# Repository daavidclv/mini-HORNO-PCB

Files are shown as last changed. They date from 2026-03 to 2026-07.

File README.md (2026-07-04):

# 🔥 Mini Horno — Diseño de PCB en KiCad

Diseño completo de PCB para un mini horno, desde el esquemático hasta los ficheros de fabricación (Gerbers).

## 📋 Descripción

Proyecto de diseño electrónico centrado en la placa de control de un mini horno: esquemático, layout, y generación de todos los archivos necesarios para su fabricación (Gerbers y taladros). Incluye la PCB ya fabricada y montada.

## 🛠️ Stack técnico

- **Diseño de PCB:** KiCad (esquemático + layout)
- **Fabricación:** Gerbers (RS-274X) + ficheros de taladro (PTH/NPTH)

## 📁 Estructura del repositorio

- `Horno.kicad_pro` / `Horno.kicad_sch` / `Horno.kicad_pcb` — proyecto KiCad completo (esquemático + layout)
- `Horno-*.gbr` — Gerbers de cada capa (cobre, máscara, pasta, serigrafía, corte)
- `Horno-PTH.drl` / `Horno-NPTH.drl` — ficheros de taladro
- `HornoGBR.zip` — paquete de fabricación listo para enviar al fabricante de PCBs

## 📸 Resultado

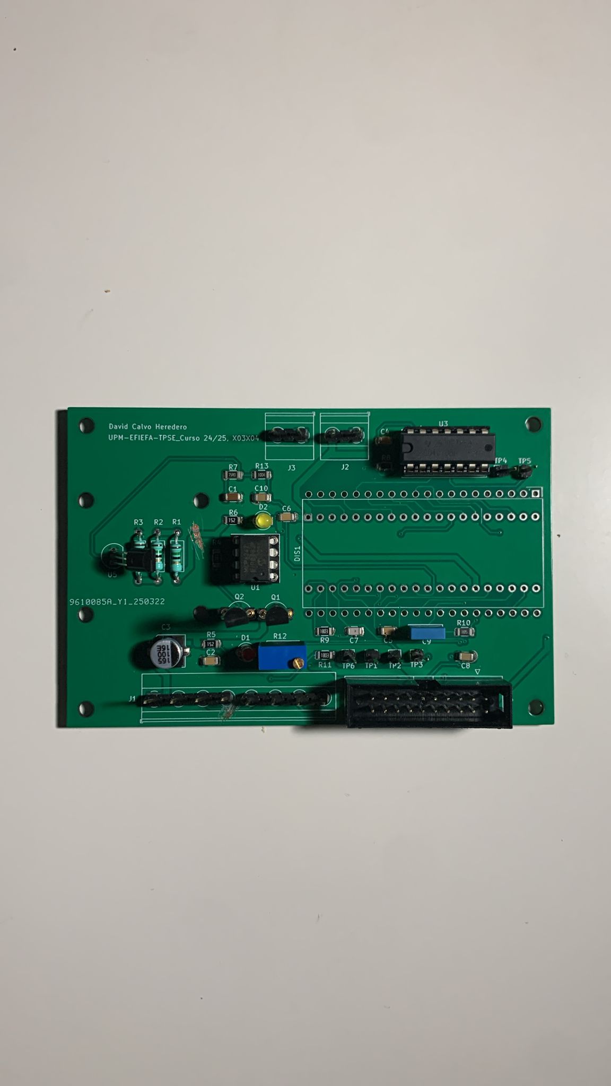
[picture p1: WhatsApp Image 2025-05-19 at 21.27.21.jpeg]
PCB del mini horno montada

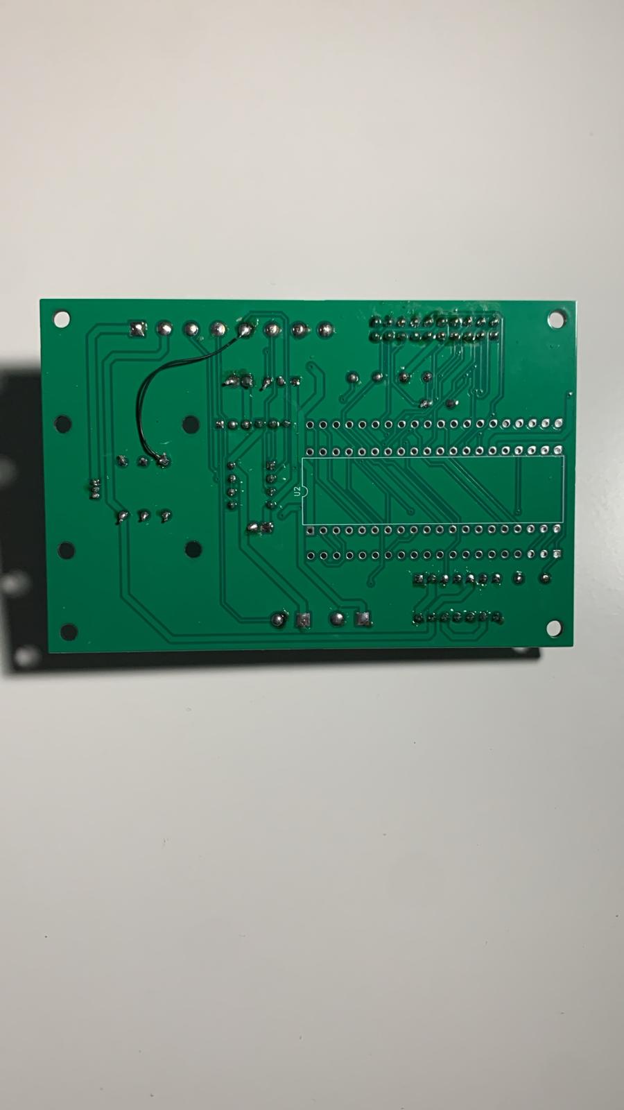
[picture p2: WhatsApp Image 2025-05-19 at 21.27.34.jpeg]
Detalle de la PCB


## 🎯 Lo más complejo del proyecto

- Diseño del layout considerando disipación térmica y separación de pistas de potencia
- Preparación del paquete completo de fabricación (Gerbers + taladros) sin errores de DRC

## 👤 Autor

David Calvo Heredero — [LinkedIn](https://www.linkedin.com/in/david-calvo-heredero-20b20a33a) · [GitHub](https://github.com/daavidclv)

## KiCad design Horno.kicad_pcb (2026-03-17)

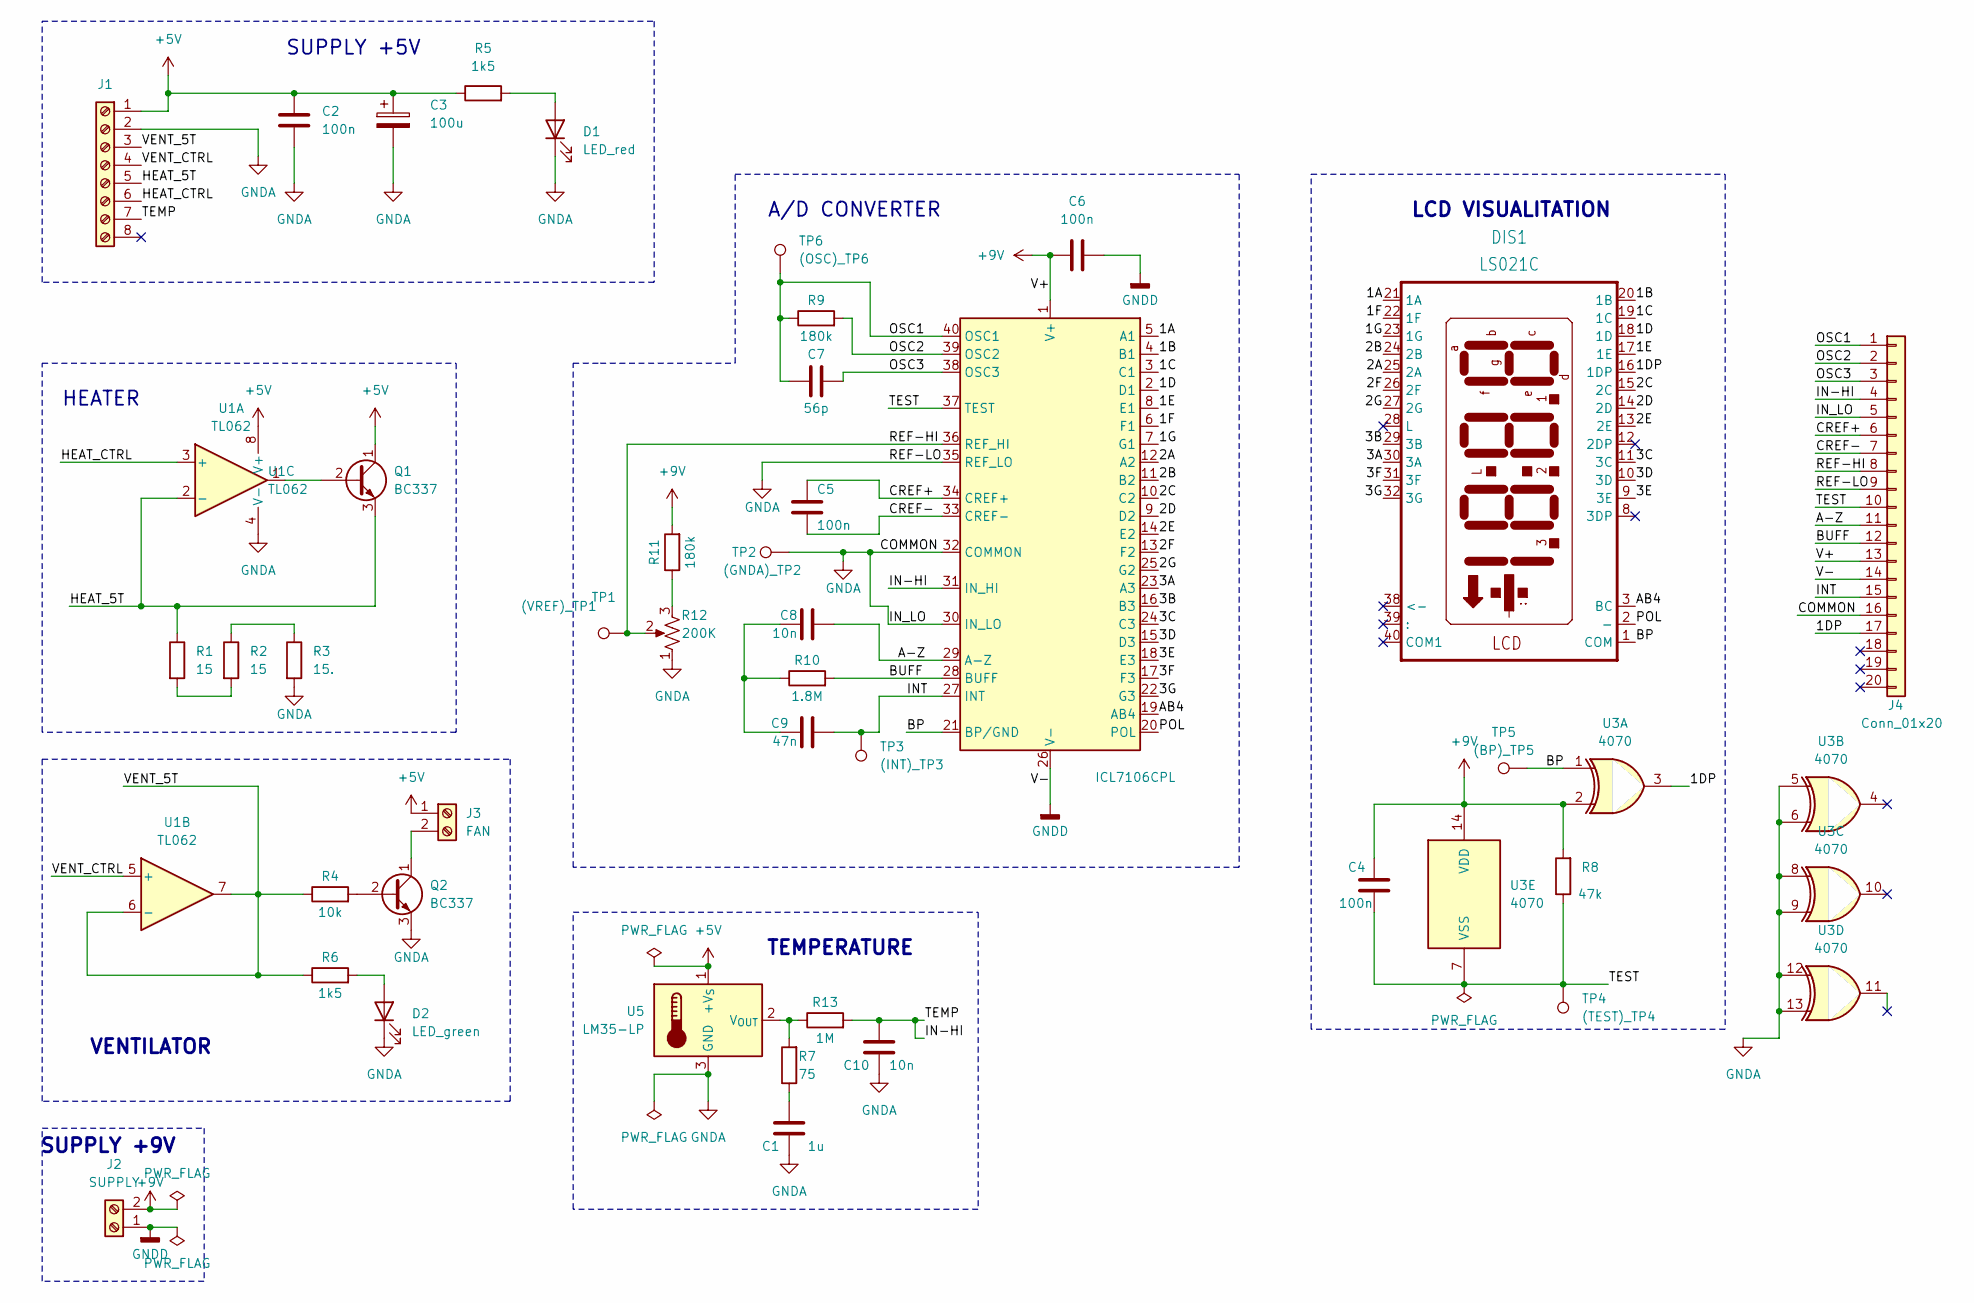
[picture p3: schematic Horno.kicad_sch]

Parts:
C1: 1u; C_1206_3216Metric
C2, C4, C5, C6: 100n; C_1206_3216Metric
C3: 100u; CP_Elec_5x3.9
C7: 56p; C_1206_3216Metric
C8, C10: 10n; C_1206_3216Metric
C9: 47n; C_Rect_L7.0mm_W2.5mm_P5.00mm
D1: LED_red; LED_D3.0mm
D2: LED_green; LED_D3.0mm
DIS1: LS021C; DELS021-XX-XX
J1: TerminalBlock_Phoenix_MKDS-1,5-8-5.08_1x08_P5.08mm_Horizont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
J2: SUPPLY; TerminalBlock_Phoenix_MKDS-1,5-2-5.08_1x02_P5.08mm_Horizont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
J3: FAN; TerminalBlock_Phoenix_MKDS-1,5-2-5.08_1x02_P5.08mm_Horizont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
J4: Conn_01x20; IDC-Header_2x10_P2.54mm_Vertical
Q1: BC337; TO-92L_Inline_Wide
Q2: BC337; TO-92_Inline_Wide
R1, R2: 15; R_Axial_DIN0207_L6.3mm_D2.5mm_P10.16mm_Horizontal
R3: 15.; R_Axial_DIN0207_L6.3mm_D2.5mm_P10.16mm_Horizontal
R4: 10k; R_1206_3216Metric
R5, R6: 1k5; R_1206_3216Metric
R7: 75; R_1206_3216Metric
R8: 47k; R_1206_3216Metric
R9, R11: 180k; R_1206_3216Metric
R10: 1.8M; R_1206_3216Metric
R12: 200K; Potentiometer_Bourns_3266Y_Vertical
R13: 1M; R_1206_3216Metric
TP1: (VREF)_TP1; Pin_D0.9mm_L10.0mm_W2.4mm_FlatFork
TP2: (GNDA)_TP2; Pin_D0.9mm_L10.0mm_W2.4mm_FlatFork
TP3: (INT)_TP3; Pin_D0.9mm_L10.0mm_W2.4mm_FlatFork
TP4: (TEST)_TP4; Pin_D0.9mm_L10.0mm_W2.4mm_FlatFork
TP5: (BP)_TP5; Pin_D0.9mm_L10.0mm_W2.4mm_FlatFork
TP6: (OSC)_TP6; Pin_D0.9mm_L10.0mm_W2.4mm_FlatFork
U1: TL062; DIP-8_W7.62mm_Socket
U2: ICL7106CPL; DIP-40_W15.24mm
U3: 4070
U5: LM35-LP; TO-92_Inline

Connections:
+5V: C2.1, C3.1, J1.1, J3.1, Q1.1 (C), R5.1, U1.8 (V+), U5.1 (+V_{S})
+9V: C4.1, C6.1, J2.2, J4.13, R8.2, R11.2, U2.1 (V+), U3.2, U3.14 (VDD)
/1A: DIS1.21 (1A), U2.5 (A1)
/1B: DIS1.20 (1B), U2.4 (B1)
/1C: DIS1.19 (1C), U2.3 (C1)
/1D: DIS1.18 (1D), U2.2 (D1)
/1DP: DIS1.16 (1DP), J4.17, U3.3
/1E: DIS1.17 (1E), U2.8 (E1)
/1F: DIS1.22 (1F), U2.6 (F1)
/1G: DIS1.23 (1G), U2.7 (G1)
/2A: DIS1.25 (2A), U2.12 (A2)
/2B: DIS1.24 (2B), U2.11 (B2)
/2C: DIS1.15 (2C), U2.10 (C2)
/2D: DIS1.14 (2D), U2.9 (D2)
/2E: DIS1.13 (2E), U2.14 (E2)
/2F: DIS1.26 (2F), U2.13 (F2)
/2G: DIS1.27 (2G), U2.25 (G2)
/3A: DIS1.30 (3A), U2.23 (A3)
/3B: DIS1.29 (3B), U2.16 (B3)
/3C: DIS1.11 (3C), U2.24 (C3)
/3D: DIS1.10 (3D), U2.15 (D3)
/3E: DIS1.9 (3E), U2.18 (E3)
/3F: DIS1.31 (3F), U2.17 (F3)
/3G: DIS1.32 (3G), U2.22 (G3)
/A-Z: C8.1, J4.11, U2.29 (A-Z)
/AB4: DIS1.3 (BC), U2.19 (AB4)
/BP: DIS1.1 (COM), TP5.1, U2.21 (BP/GND), U3.1
/BUFF: J4.12, R10.2, U2.28 (BUFF)
/CREF+: C5.2, J4.6, U2.34 (CREF+)
/CREF-: C5.1, J4.7, U2.33 (CREF-)
/HEAT_CTRL: J1.6, U1.3 (+)
/IN-HI: C10.1, J1.7, J4.4, R13.2, U2.31 (IN_HI)
/INT: C9.1, J4.15, TP3.1, U2.27 (INT)
/OSC1: C7.1, J4.1, R9.1, TP6.1, U2.40 (OSC1)
/OSC2: J4.2, R9.2, U2.39 (OSC2)
/OSC3: C7.2, J4.3, U2.38 (OSC3)
/POL: DIS1.2 (-), U2.20 (POL)
/REF-HI: J4.8, R12.2, TP1.1, U2.36 (REF_HI)
/TEST: C4.2, J4.10, R8.1, TP4.1, U2.37 (TEST), U3.7 (VSS)
/VENT_CTRL: J1.4, U1.5 (+)
GNDA: C1.2, C2.2, C3.2, C10.2, D1.1 (K), D2.1 (K), J1.2, J4.5, J4.9, J4.16, Q2.3 (E), R3.2, R12.1, TP2.1, U1.4 (V-), U2.30 (IN_LO), U2.32 (COMMON), U2.35 (REF_LO), U3.5, U3.6, U3.8, U3.9, U3.12, U3.13, U5.3 (GND)
GNDD: C6.2, J2.1, J4.14, U2.26 (V-)
unnamed: C1.1, R7.1
unnamed: C8.2, C9.2, R10.1
unnamed: D1.2 (A), R5.2
unnamed: D2.2 (A), R6.2
unnamed: J3.2, Q2.1 (C)
unnamed: Q1.2 (B), U1.1
unnamed: Q2.2 (B), R4.2
unnamed: R1.2, R2.2
unnamed: R2.1, R3.1
unnamed: R11.1, R12.3
unnamed: R7.2, R13.1, U5.2 (V_{OUT})

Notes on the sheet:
A/D CONVERTER
TEMPERATURE
VENTILATOR
LCD VISUALITATION
SUPPLY +9V
HEATER
SUPPLY +5V

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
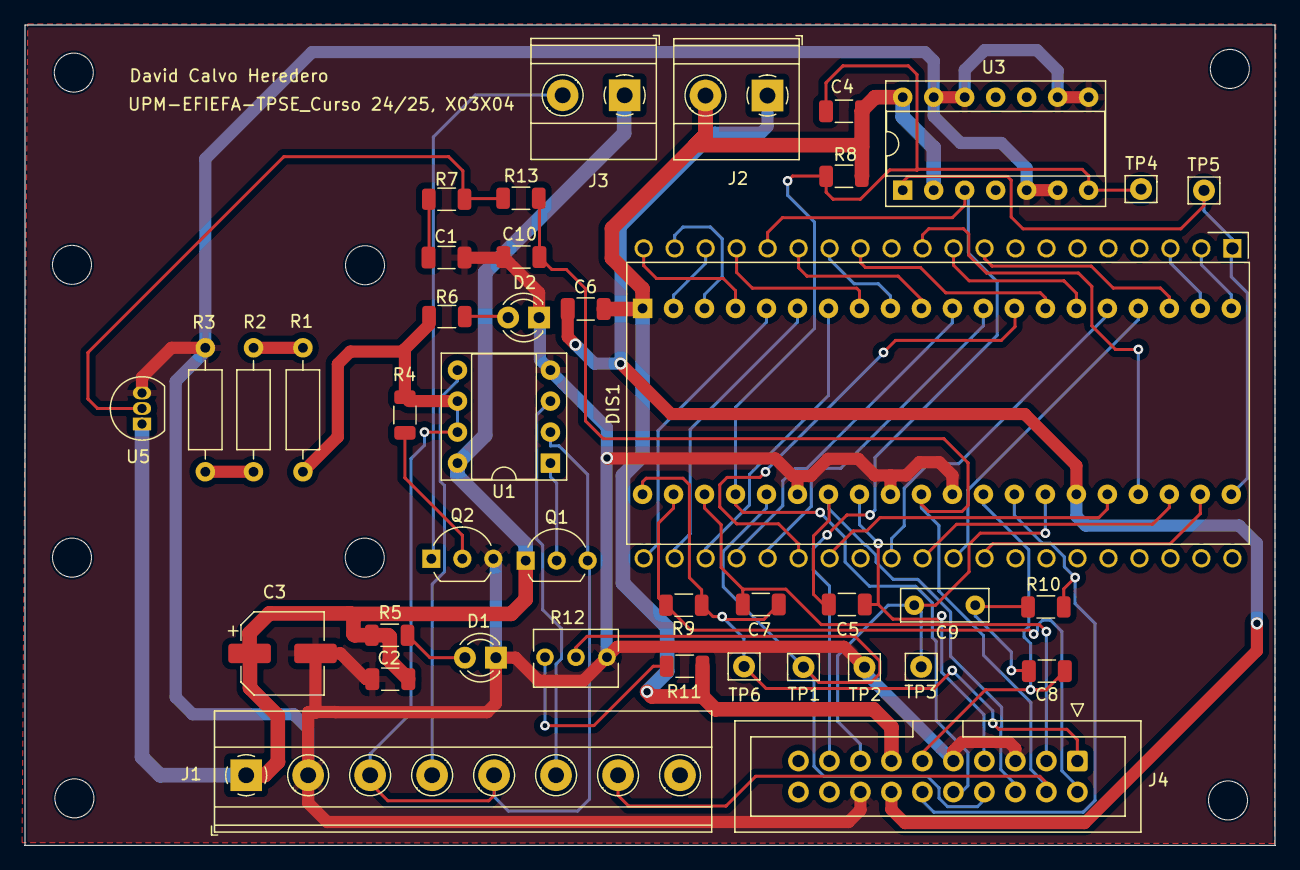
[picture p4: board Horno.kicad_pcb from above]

Board: 2 copper layers, 102.5 x 67.2 mm, 50 parts (1 on the bottom side), 54 nets.

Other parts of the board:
PATA 1, PATA 2, PATA 3, PATA 4: MountingHole_3.2mm_M3
VENT 1, VENT 2, VENT 3, VENT 4: MountingHole_3.2mm_M3
